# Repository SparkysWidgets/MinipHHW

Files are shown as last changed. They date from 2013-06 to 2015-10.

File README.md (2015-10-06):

Welcome To: MinipH Hardware Repo!!
================================

##### Note: This is for the MinipH Hardware Version 4 Branch

MinipH Hardware Design Files in EAGLE. Not much to say, there are some custom parts will add Library after I clean it up!

Schematic Info
-------------------------
##### Basic schematic is split into sections
- Analog Front End - pH gain and offset stages
- 12bit ADC
- VREF
- VGND generated by Op-amp, probe is biased
- Reverse V protection pFET

Board Layout Info
-------------------------
##### Form factor is consistent with all other mini interface boards

- Standard 2.54mm pitch header and Grove style connector
- Guard ring on pH input stage, care must be taken in layout here
- Added back in solder bridge jumper to select if Vref should be used or not (Its an expensive BurrBrown guy and really only needed for super sensitive use)

Errata
-------------------------

##### Just a quick list of current issues
- Mostly stable design older errata resolved, new may be created will be updated

Firmware
-------------------------

- Take a look in [MinipH's Firmware Repo](https://github.com/SparkysWidgets/MinipHBFW) For Arduino!
- Check out my USB pH interface[LeoPhi](https://www.sparkyswidgets.com/portfolio-item/leophi-usb-arduino-ph-sensor/) for a powerful and easy to use USB PH Probe interface!

Basic Usage
-------------------------

####See [MinipH's Firmware Repo](https://github.com/SparkysWidgets/MinipHBFW)

License Info
-------------------------

<p>This is a fully open source project released under the CC BY license</p>
<br />
<span xmlns:dct="http://purl.org/dc/terms/" property="dct:title">MinipH</span> by <a xmlns:cc="http://creativecommons.org/ns#" href="www.sparkyswidgets.com" property="cc:attributionName" rel="cc:attributionURL">Ryan Edwards, Sparky's Widgets</a> is licensed under a <a rel="license" href="http://creativecommons.org/licenses/by-sa/3.0/deed.en_US">Creative Commons Attribution-ShareAlike 3.0 Unported License</a>.<br />
Based on a work at <a xmlns:dct="http://purl.org/dc/terms/" href="/portfolio-item/leophi-usb-arduino-ph-sensor/" rel="dct:source">http://www.sparkyswidgets.com/portfolio-item/miniph-i2c-ph-interface/</a>

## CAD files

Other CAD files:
MinipHV4_0.skp

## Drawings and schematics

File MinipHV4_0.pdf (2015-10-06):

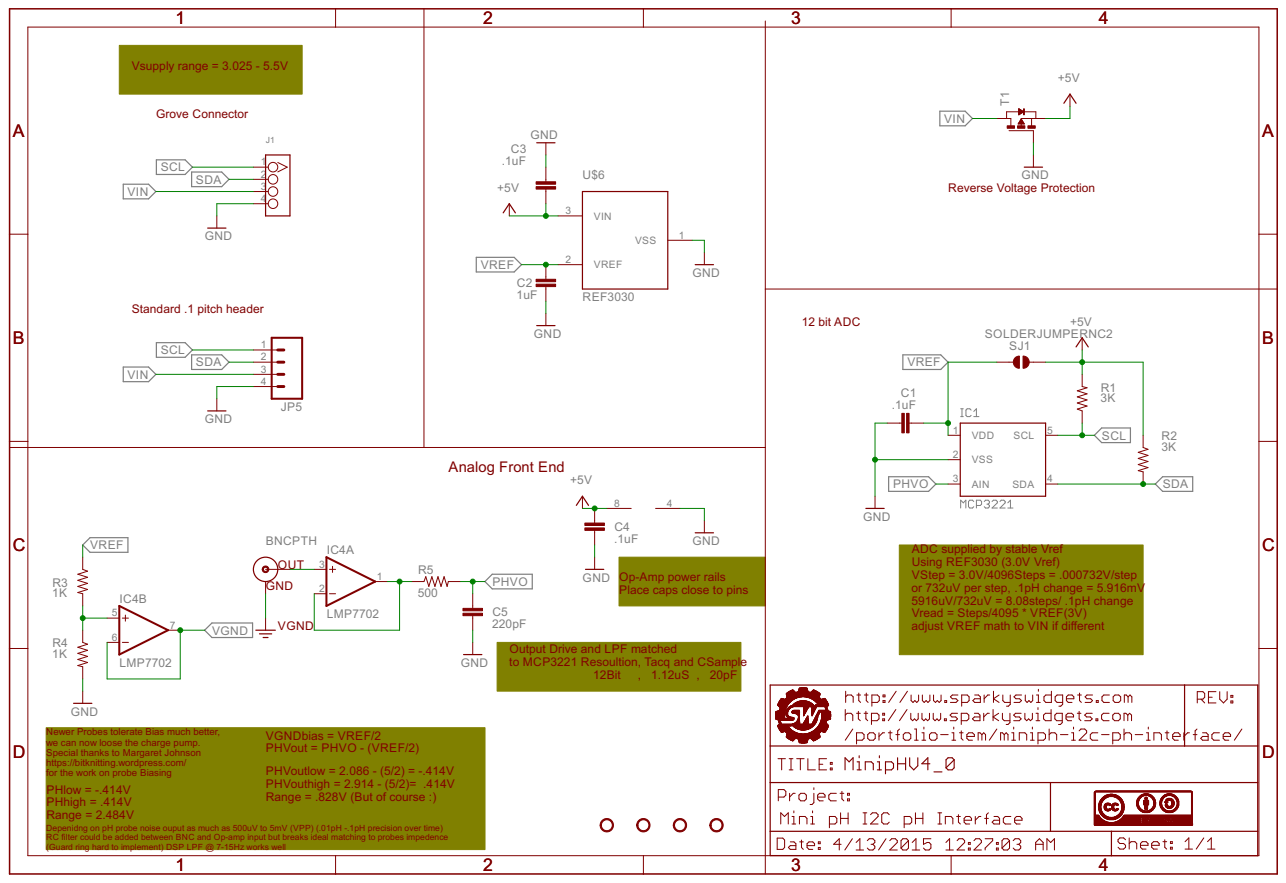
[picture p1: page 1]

ADC supplied by stable Vref
Using REF3030 (3.0V Vref)
VStep = 3.0V/4096Steps = .000732V/step
or 732uV per step, .1pH change = 5.916mV
5916uV/732uV = 8.08steps/ .1pH change Vread = Steps/4095 * VREF(3V) adjust VREF math to VIN if different

Op-Amp power rails Place caps close to pins

Output Drive and LPF matched
to MCP3221 Resoultion, Tacq and CSample

Newer Probes tolerate Bias much better, we can now loose the charge pump. Special thanks to Margaret Johnson

https://bitknitting.wordpress.com/

PHVoutlow = 2.086 - (5/2) = -.414V
PHVouthigh = 2.914 - (5/2)= .414V
Range = .828V (But of course :)

Depenidng on pH probe noise ouput as much as 500uV to 5mV (VPP) (.01pH -.1pH precision over time) RC filter could be added between BNC and Op-amp input but breaks ideal matching to probes impedence

(Guard ring hard to implement) DSP LPF @ 7-15Hz works well

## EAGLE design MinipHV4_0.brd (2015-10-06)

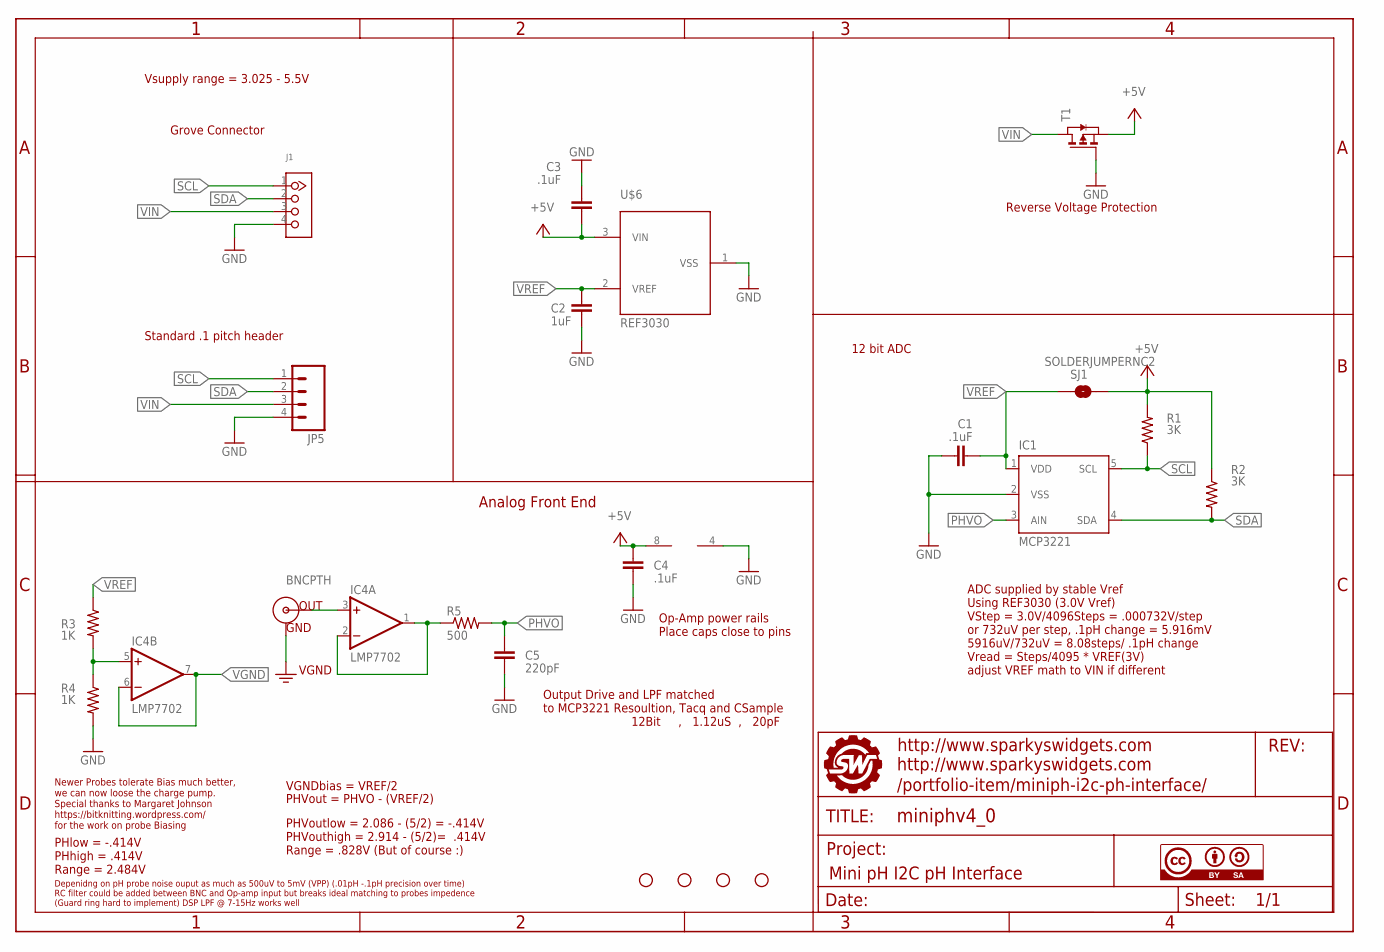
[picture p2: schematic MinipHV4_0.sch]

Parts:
C1, C3, C4: .1uF; 0805
C2: 1uF; 0805
C5: 220pF; 0805
IC1: MCP3221; SOT23-DBV
IC4: LMP7702; SO08
J1: TWIG-4P-2.0-2.0; 4P-2.0
JP1, JP2, JP3, JP4: STAND-OFF
JP5: M04PTH; 1X04
R1, R2: 3K; 0805
R3, R4: 1K; 0805
R5: 500; 0805
SJ1: SOLDERJUMPERNC2; SJ_2S-NOTRACE
T1: PMOSSOT23; SOT-23
U$2: BNCPTH; BNC
U$4: FRAME_MINIPH; SWPCBLOGOWITHINFO
U$5: CC-BY-SA
U$6: REF3030; SOT-23

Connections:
+5V: C3.1, C4.1, IC4.8 (V+), R1.2, R2.1, SJ1.2, T1.2 (S), U$6.3 (VIN)
GND: C1.1, C2.2, C3.2, C4.2, C5.2, IC1.2 (VSS), IC4.4 (V-), J1.4, JP5.4, R4.2, T1.3 (G), U$6.1 (VSS)
unnamed: IC4.5 (+IN), R3.2, R4.1
unnamed: IC4.1 (OUT), IC4.2 (-IN), R5.1
PHVIN: IC4.3 (+IN), U$2.S (OUT)
PHVO: C5.1, IC1.3 (AIN), R5.2
SCL: IC1.5 (SCL), J1.1, JP5.1, R1.1
SDA: IC1.4 (SDA), J1.2, JP5.2, R2.2
VGND: IC4.6 (-IN), IC4.7 (OUT), U$2.GND
VIN: J1.3, JP5.3, T1.1 (D)
VREF: C1.2, C2.1, IC1.1 (VDD), R3.1, SJ1.1, U$6.2 (VREF)

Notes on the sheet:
Grove Connector
Standard .1 pitch header
12 bit ADC
Analog Front End
Op-Amp power rails Place caps close to pins
Depenidng on pH probe noise ouput as much as 500uV to 5mV (VPP) (.01pH -.1pH precision over time) RC filter could be added between BNC and Op-amp input but breaks ideal matching to probes impedence (Guard ring hard to implement) DSP LPF @ 7-15Hz works well
Newer Probes tolerate Bias much better, we can now loose the charge pump. Special thanks to Margaret Johnson https://bitknitting.wordpress.com/ for the work on probe Biasing
VGNDbias = VREF/2
PHVout = PHVO - (VREF/2)
PHlow = -.414V PHhigh = .414V Range = 2.484V
PHVoutlow = 2.086 - (5/2) = -.414V PHVouthigh = 2.914 - (5/2)= .414V Range = .828V (But of course :)
Output Drive and LPF matched to MCP3221 Resoultion, Tacq and CSample 12Bit , 1.12uS , 20pF
Vsupply range = 3.025 - 5.5V
ADC supplied by stable Vref Using REF3030 (3.0V Vref) VStep = 3.0V/4096Steps = .000732V/step or 732uV per step, .1pH change = 5.916mV 5916uV/732uV = 8.08steps/ .1pH change Vread = Steps/4095 * VREF(3V) adjust VREF math to VIN if different
Reverse Voltage Protection

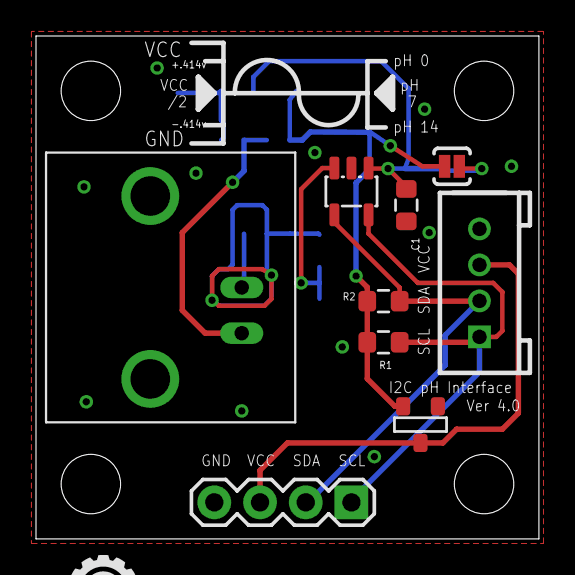
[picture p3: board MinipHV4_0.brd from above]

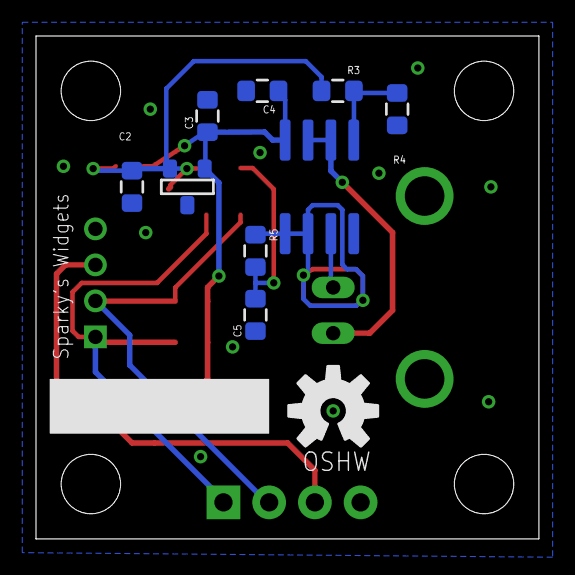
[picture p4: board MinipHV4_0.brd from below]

Board: 2 copper layers, 27.9 x 27.9 mm, 27 parts (10 on the bottom side), 11 nets.

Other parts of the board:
U$1, U$7: SILK_ARROW
U$3: OSHW-LOGO-M

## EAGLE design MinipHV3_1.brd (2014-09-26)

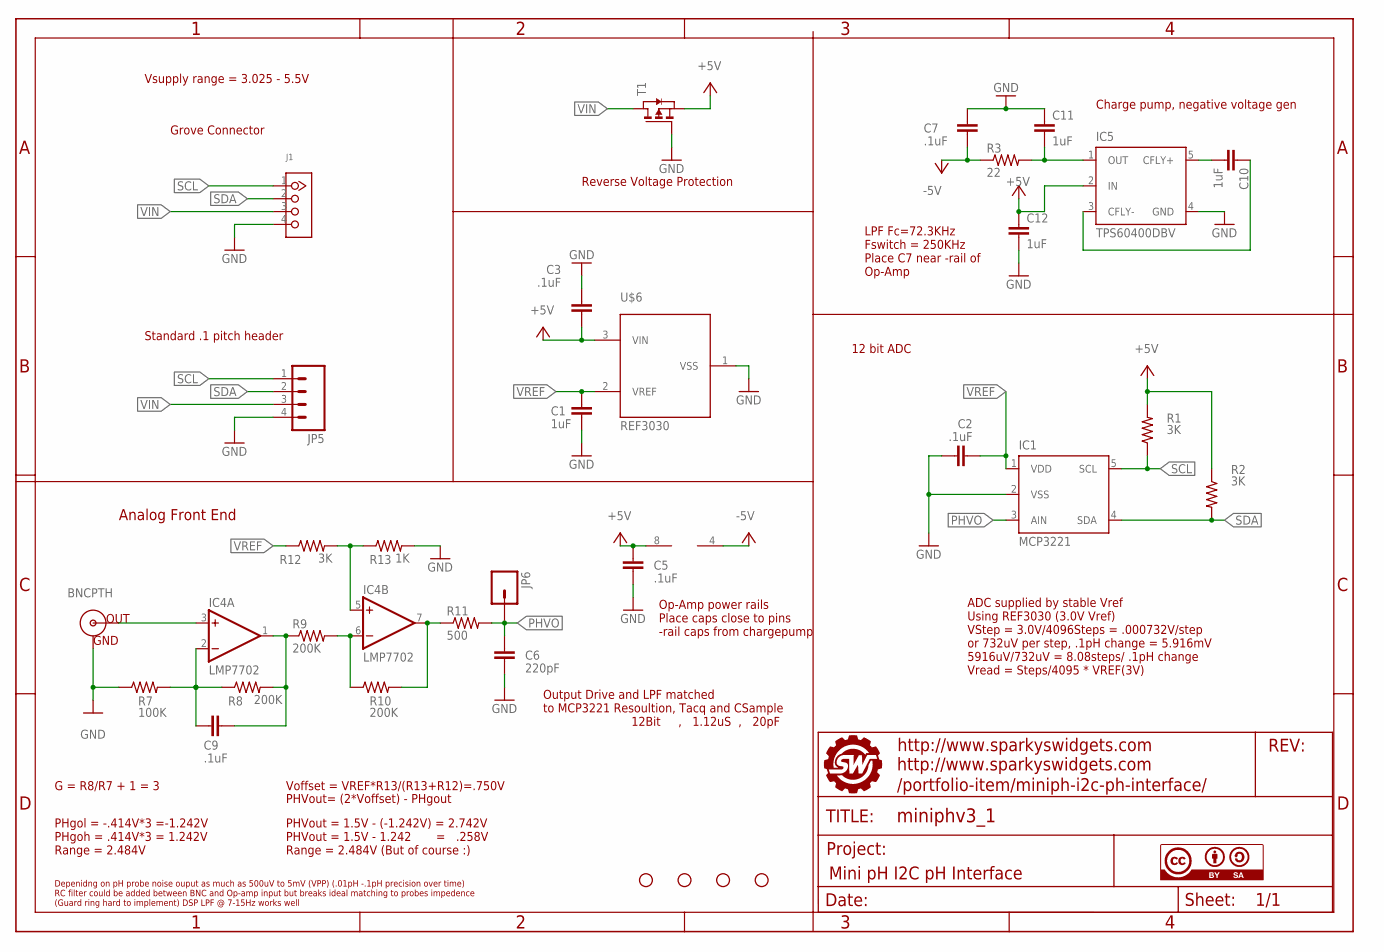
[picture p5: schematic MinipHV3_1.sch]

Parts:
C1, C10, C11, C12: 1uF; 0805
C2, C3, C5, C7, C9: .1uF; 0805
C6: 220pF; 0805
IC1: MCP3221; SOT23-DBV
IC4: LMP7702; SO08
IC5: TPS60400DBV; SOT23-DBV
J1: TWIG-4P-2.0-2.0; 4P-2.0
JP1, JP2, JP3, JP4: STAND-OFF
JP5: M04PTH; 1X04
JP6: M01PTH; 1X01
R1, R2, R12: 3K; 0805
R3: 22; 0805
R7: 100K; 0805
R8, R9, R10: 200K; 0805
R11: 500; 0805
R13: 1K; 0805
T1: PMOSSOT23; SOT-23
U$2: BNCPTH; BNC
U$4: FRAME_MINIPH; SWPCBLOGOWITHINFO
U$5: CC-BY-SA
U$6: REF3030; SOT-23

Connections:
+5V: C3.1, C5.1, C12.1, IC4.8 (V+), IC5.2 (IN), R1.2, R2.1, T1.2 (S), U$6.3 (VIN)
-5V: C7.2, IC4.4 (V-), R3.1
GND: C1.2, C2.1, C3.2, C5.2, C6.2, C7.1, C11.1, C12.2, IC1.2 (VSS), IC5.4 (GND), J1.4, JP5.4, R7.1, R13.2, T1.3 (G), U$2.GND, U$6.1 (VSS)
unnamed: IC4.5 (+IN), R12.2, R13.1
unnamed: IC4.7 (OUT), R10.2, R11.1
unnamed: IC4.6 (-IN), R9.2, R10.1
unnamed: C11.2, IC5.1 (OUT), R3.2
unnamed: C9.2, IC4.2 (-IN), R7.2, R8.1
unnamed: IC4.3 (+IN), U$2.S (OUT)
unnamed: C9.1, IC4.1 (OUT), R8.2, R9.1
unnamed: C10.1, IC5.3 (CFLY-)
unnamed: C10.2, IC5.5 (CFLY+)
PHVO: C6.1, IC1.3 (AIN), JP6.1, R11.2
SCL: IC1.5 (SCL), J1.1, JP5.1, R1.1
SDA: IC1.4 (SDA), J1.2, JP5.2, R2.2
VIN: J1.3, JP5.3, T1.1 (D)
VREF: C1.1, C2.2, IC1.1 (VDD), R12.1, U$6.2 (VREF)

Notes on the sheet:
Grove Connector
Standard .1 pitch header
12 bit ADC
Charge pump, negative voltage gen
Analog Front End
Op-Amp power rails Place caps close to pins -rail caps from chargepump
Depenidng on pH probe noise ouput as much as 500uV to 5mV (VPP) (.01pH -.1pH precision over time) RC filter could be added between BNC and Op-amp input but breaks ideal matching to probes impedence (Guard ring hard to implement) DSP LPF @ 7-15Hz works well
G = R8/R7 + 1 = 3
Voffset = VREF*R13/(R13+R12)=.750V
PHVout= (2*Voffset) - PHgout
PHgol = -.414V*3 =-1.242V PHgoh = .414V*3 = 1.242V Range = 2.484V
PHVout = 1.5V - (-1.242V) = 2.742V PHVout = 1.5V - 1.242 = .258V Range = 2.484V (But of course :)
Output Drive and LPF matched to MCP3221 Resoultion, Tacq and CSample 12Bit , 1.12uS , 20pF
Vsupply range = 3.025 - 5.5V
LPF Fc=72.3KHz Fswitch = 250KHz Place C7 near -rail of Op-Amp
ADC supplied by stable Vref Using REF3030 (3.0V Vref) VStep = 3.0V/4096Steps = .000732V/step or 732uV per step, .1pH change = 5.916mV 5916uV/732uV = 8.08steps/ .1pH change Vread = Steps/4095 * VREF(3V)
Reverse Voltage Protection

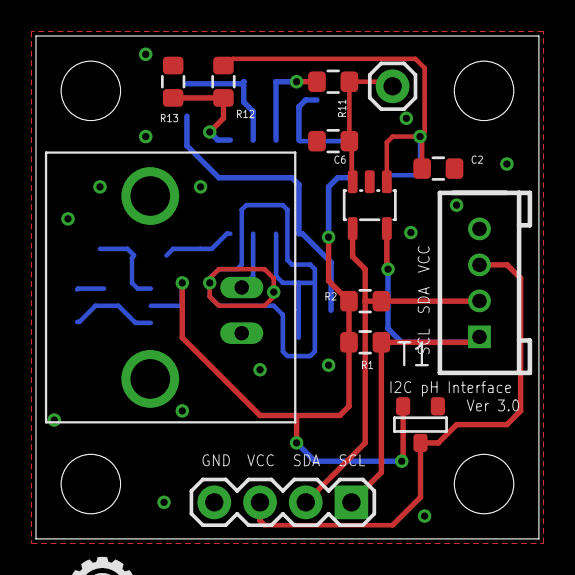
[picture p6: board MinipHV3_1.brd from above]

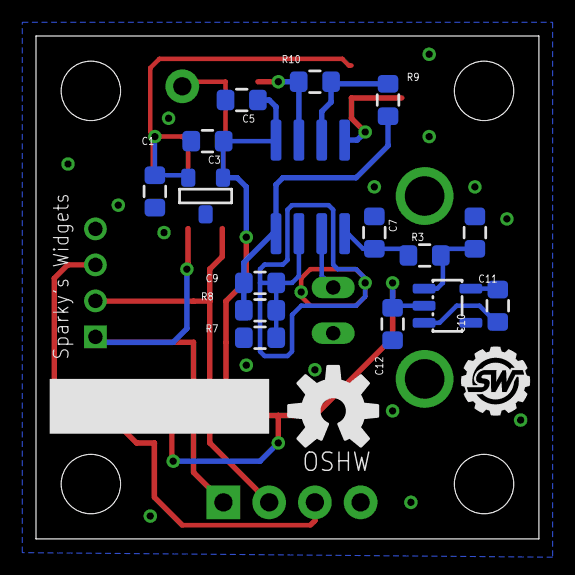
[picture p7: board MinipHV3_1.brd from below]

Board: 2 copper layers, 27.9 x 27.9 mm, 37 parts (18 on the bottom side), 17 nets.

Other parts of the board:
U$1: SWPCBLOGO
U$3: OSHW-LOGO-M

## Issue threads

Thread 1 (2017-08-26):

MinipHHW v4.0 opamp design doesn't work

danlu01, 2017-08-26:
Looking at miniph v4.0, the opamp design have changed from previous version.  I don't understand how v4.0 can work without opamp gain resisters to boost the voltage from the pH probe.

Hexor38, 2019-02-13:
Hi danlu01,

Do you already test the v4.0 board or "just" analyse the schematic ? I'm interested by this project.

FlynnMa, 2022-10-30:
This project seems no longer maintained

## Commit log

2013-04-23 Added Design Files
    [MinipHV0_1.brd, MinipHV0_1.sch]
2013-04-23 updated design files to v2_1
    [MinipHV0_1.brd, MinipHV0_1.sch, MinipHV2_1.brd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]
2013-06-04 updated schematic
    [MinipHV2_1.brd, MinipHV2_1.sch]
2014-09-26 Cleaned up design a bit, added changed to readme
    [MinipHV3_1.brd, MinipHV3_1.sch]
2014-09-26 added in bridge jumper VCC to Vref
    [MinipHV3_2.brd, MinipHV3_2.sch]
2015-01-19 Added sch in pdf form and skethup 3d model
    [MinipHV3_2.skp]
2015-10-06 Updated to version 4.0
    [MinipHV3_2.brd, MinipHV3_2.sch, MinipHV3_2.skp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]

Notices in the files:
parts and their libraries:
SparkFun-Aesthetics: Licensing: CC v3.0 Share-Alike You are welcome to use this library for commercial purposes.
